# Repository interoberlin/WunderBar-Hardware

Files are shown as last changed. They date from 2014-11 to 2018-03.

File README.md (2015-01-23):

The WunderBar Schematics and Layout Repository
------------

Welcome to the **WunderBar Hardware Schematics and Layout** repository.
This repository contains the latest version of the *[WunderBar](https://relayr.io/wunderbar)* hardware design.
The *WunderBar* is manufactured by *[MikroElektronika](http://www.mikroe.com/wunderbar)*.   Manufacturing was sponsored by *[Conrad Electronics](http://www.conrad.de)*.

Here you will find everything you need to build your own version of the WunderBar. We encourage you to share, modify, extend and improve the existing design. Please reach out to us if you have any questions or need any help. We are eager to hear your feedback about the design, and suggestions as to how we might improve it.

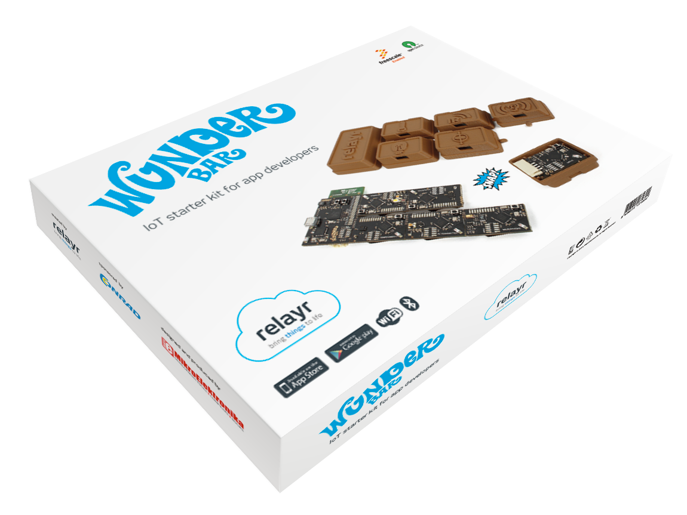
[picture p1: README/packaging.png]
WunderBar

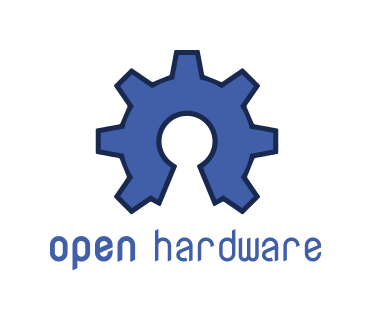
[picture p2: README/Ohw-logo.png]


### Datasheets:
In the *[/Datasheets](https://github.com/relayr/wunderbar-hardware/tree/master/Datasheets)* folder you will find the relevant data sheets for the micro controller units (MCUs), the sensors and the additional circuitry, separated by module type.

### Schematics:
The complete project for [*Altium Designer* <sup>TM</sup>](http://www.altium.com/altium-designer/overview) is located in the *[AltiumDesignerProject](https://github.com/relayr/wunderbar-hardware/tree/master/AltiumDesignerProject)* folder.

For a quick overview of the schematics for the Master Module and the 6 BLE modules, see the  *[WunderBar Schematics v1_3.pdf file](https://github.com/relayr/wunderbar-hardware/blob/master/WunderBar%20Schematics%20v1_3.pdf)*.

### Layout:
A PDF output of the PCB Layout can be found under *[Wunderbar Layout.pdf](https://github.com/relayr/wunderbar-hardware/blob/master/WunerBar%20Layout%20v1_3.pdf)*. For a detailed view of the different layers and connections see the *[Altium](http://www.altium.com/altium-designer/overview)* project.

### Bill of Materials:
The *[Bill of Materials v1_3](https://github.com/relayr/wunderbar-hardware/blob/master/Bill%20of%20Materials%20v1_3.xls)* sheet details the components' names, quantities, the suppliers' names and part numbers. See also the two files under *[/Manufacturing/BillOfMaterials](https://github.com/relayr/wunderbar-hardware/tree/master/Manufacturing/BillOfMaterials)* for a list view of the information in the Schematics file.

### Gerber Files:
The Gerber files output and the 'Pick and Place' configuration files are located inside the [*/Manufacturing*](https://github.com/relayr/wunderbar-hardware/tree/master/Manufacturing) folder.

### Acquiring the Files:
* To get the entire repository, download it as a **.zip** file from [here](https://github.com/relayr/wunderbar-hardware/archive/master.zip).

or

* If you have **git** installed simply access the folder where you want to download it and enter the following command:

	`git clone https://github.com/relayr/wunderbar-hardware.git`

We hope that you'd utilize the Wunderbar in your future projects. The realm of possibilities is as vast as your imagination!!!

### License:

	Copyright (c) 2014, Press Any Key UG and iThings4U GmbH

	All rights reserved.

	Redistribution and use in source and binary forms, with or without
	modification, are permitted provided that the following conditions are met:

	1. Redistributions of source code must retain the above copyright notice,
	this list of conditions and the following disclaimer.

	2. Redistributions in binary form must reproduce the above copyright notice,
	this list of conditions and the following disclaimer in the documentation
	and/or other materials provided with the distribution.

	3. Neither the name of the copyright holder nor the names of its contributors
	may be used to endorse or promote products derived from this software without
	specific prior written permission.

	THIS SOFTWARE IS PROVIDED BY THE COPYRIGHT HOLDERS AND CONTRIBUTORS "AS IS"
	AND ANY EXPRESS OR IMPLIED WARRANTIES, INCLUDING, BUT NOT LIMITED TO,
	THE IMPLIED WARRANTIES OF MERCHANTABILITY AND FITNESS FOR A PARTICULAR
	PURPOSE ARE DISCLAIMED. IN NO EVENT SHALL THE COPYRIGHT HOLDER OR CONTRIBUTORS
	BE LIABLE FOR ANY DIRECT, INDIRECT, INCIDENTAL, SPECIAL, EXEMPLARY,
	OR CONSEQUENTIAL DAMAGES (INCLUDING, BUT NOT LIMITED TO, PROCUREMENT
	OF SUBSTITUTE GOODS OR SERVICES; LOSS OF USE, DATA, OR PROFITS; OR BUSINESS
	INTERRUPTION) HOWEVER CAUSED AND ON ANY THEORY OF LIABILITY, WHETHER IN
	CONTRACT, STRICT LIABILITY, OR TORT (INCLUDING NEGLIGENCE OR OTHERWISE)
	ARISING IN ANY WAY OUT OF THE USE OF THIS SOFTWARE, EVEN IF ADVISED OF
	THE POSSIBILITY OF SUCH DAMAGE.

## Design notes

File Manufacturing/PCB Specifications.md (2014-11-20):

WunderBar Hardware
------------

### PCB Specifications:
* Material: FR-4,
* Thickness: 1.6mm,
* Layer count:4-layer,
* Extra details: Immersion Gold, 1oz finished copper, Black SolderMask, White Legend.

####NOTES:
* Layer sequence: GTL-G1-G2-GBL
* This design has blind bias: TX1 file represent holes between GTL and G1 layers

* We made the board panelized (3up) with 10mm routing between the boards vertically
* Panel Border should be 7mm wide with fiducial marks and tooling holes (3mm) distanced 2.5mm from the inner edge
* The size of the board is 115.723mm (W) x 39.421mm (H)
* The size of the panel should be 129.723mm (W) x 138.263mm (H)

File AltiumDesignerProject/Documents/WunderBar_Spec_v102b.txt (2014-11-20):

Specification:
FR-4, 1.6mm, 4-layer, Immersion Gold, 1oz finished copper, Black SolderMask, White Legend.
NOTES:
- Layer sequence: GTL-G1-G2-GBL
- This design has blind vias: TX1 file represent holes between GTL and G1 layers
- We need this board panelized (3up) with 10mm routing between the boards vertically
- Panel Border should be 7mm wide with fiducial marks and tooling holes (3mm) distanced 2.5mm from the inner edge
- NOTE: Panel already done
- The size of the board is 115.723mm (W) x 39.421mm (H)
- The size of the panel should be 129.723mm (W) x 138.263mm (H)

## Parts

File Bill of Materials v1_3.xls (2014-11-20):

# | Item Name | Quantity | Supplier Name | Package | Part Number
1 | 2450AT18A100E ANTENNA CHIP 2.4GHz SMD | 7 | DIGI-KEY CORPORATION | Tape & Reel (3Kpcs per Reel) | 2450AT18A100E
2 | 2450BM14A0002T 2.45Ghz balun low pass filter | 7 | DIGI-KEY CORPORATION | Tape & Reel (3Kpcs per Reel) | 2450BM140002T
3 | Battery Holder COIN CELL 20MM SMD | 5 | DIGI-KEY CORPORATION | Tape & Reel (700pcs per Reel) | BK-912-TR-ND
4 | Connector Header 2-pin for Li-Poly Battery SMD | 1 | DIGI-KEY CORPORATION | Tape & Reel (1Kpcs per Reel) | 455-1749-2-ND
5 | NRF51822-QFAA-G0 Bluetooth v4.0, Low Energy 48QFN SMD | 7 | RUTRONIK Elektronische Bauelemente GmbH | Tape & Reel (3Kpcs per Reel) | BTOOTH1233
6 | Tact Switch 4.60mm x 2.80mm SMD | 8 | DIGI-KEY CORPORATION | Digi-Reel | CKN10244DKR-ND
7 | 1nF Capacitor 0402 SMD | 14 | RUTRONIK Elektronische Bauelemente GmbH | Tape & Reel (10Kpcs per Reel) | KKK14629
8 | 100nF Capacitor 0402 SMD | 38 | RUTRONIK Elektronische Bauelemente GmbH | Tape & Reel (10Kpcs per Reel) | KKK16522
9 | 10uF Capacitor 0603 SMD | 14 | RUTRONIK Elektronische Bauelemente GmbH | Tape & Reel (4Kpcs per Reel) | KKS1047
10 | 10pF Capacitor 0402 SMD | 15 | RUTRONIK Elektronische Bauelemente GmbH | Tape & Reel (10Kpcs per Reel) | KKK14556
11 | 47nF Capacitor 0402 SMD | 7 | RUTRONIK Elektronische Bauelemente GmbH | Tape & Reel (10Kpcs per Reel) | KKK20252
12 | 12pF Capacitor 0402 SMD | 18 | RUTRONIK Elektronische Bauelemente GmbH | Tape & Reel (10Kpcs per Reel) | KKK14879
13 | 1uF Capacitor 0402 SMD | 5 | RUTRONIK Elektronische Bauelemente GmbH | Tape & Reel (10Kpcs per Reel) | KKS3215
14 | 10nF Capacitor 0402 SMD | 1 | RUTRONIK Elektronische Bauelemente GmbH | Tape & Reel (10Kpcs per Reel) | KKK16335
15 | 8pF Capacitor 0402 SMD | 1 | DIGI-KEY CORPORATION | Tape & Reel (10Kpcs per Reel) | 445-4891-2-ND
16 | 2.2uF Capacitor 0603 SMD | 1 | RUTRONIK Elektronische Bauelemente GmbH | Tape & Reel (4Kpcs per Reel) | KKK18480
17 | SD0603S040S0R2 DIODE SCHOTTKY 40V 0.2A 0603 SMD | 1 | DIGI-KEY CORPORATION | Tape & Reel (3Kpcs per Reel) | 478-7798-2-ND
18 | PCA9306 I2C Voltage translator US8 SMD | 1 | DIGI-KEY CORPORATION | Tape & Reel (3Kpcs per Reel) | 296-17988-2-ND
19 | ZXLD383 LED driver white backlght SOT23-5 SMD | 1 | DIGI-KEY CORPORATION | Tape & Reel (3Kpcs per Reel) | ZXLD383ET5TR-ND
20 | 10uH Inductor 4x4mm 1.2A SMD | 1 | DIGI-KEY CORPORATION | Tape & Reel (3500pcs per Reel) | 587-2886-2-ND
21 | 47uH Inductor 20% 75mA 0805 SMD | 1 | DIGI-KEY CORPORATION | Tape & Reel (3Kpcs per Reel) | 587-2047-2-ND
22 | LED Yellow - 0402 SMD | 10 | DIGI-KEY CORPORATION | Tape & Reel (2Kpcs per Reel) | SML-LX0402SYC-TR
23 | SFH4441 LED IR EMITTER 950NM SMD | 2 | MOUSER ELECTRONICS | Tape & Reel (3Kpcs per Reel) | 720-SFH4441
24 | LED White - 1206 SMD | 1 | DIGI-KEY CORPORATION | Tape & Reel (2Kpcs per Reel) | 45-21/LK2C-B38452C4CB2/2T
25 | Grove connector 4pin original 1125R-4P | 1 | Seeed Technology Inc. | Bulk (10pcs per pack) | 1125R-4P
26 | LTC4081DFN Li-Ion battery charger and buck regulator SMD | 1 | DIGI-KEY CORPORATION | Tape & Reel | LTC4081EDD#TRPBF
27 | 95K3 ohm Resistor 0402 SMD | 1 | DIGI-KEY CORPORATION | Tape & Reel (10Kpcs per Reel) | RMCF0402FT95K3TR-ND
28 | 300K ohm Resistor 0402 SMD | 1 | DIGI-KEY CORPORATION | Tape & Reel (10Kpcs per Reel) | 311-300KLRTR-ND
29 | 1K69 Ohm Resistor 0402 SMD | 1 | RUTRONIK Elektronische Bauelemente GmbH | Tape & Reel (10Kpcs per Reel) | WRC47924
30 | 220 ohm Resistor 0402 SMD | 1 | RUTRONIK Elektronische Bauelemente GmbH | Tape & Reel (10Kpcs per Reel) | WRC33968
31 | 22 ohm Resistor 0402 SMD | 3 | RUTRONIK Elektronische Bauelemente GmbH | Tape & Reel (10Kpcs per Reel) | WRC33949
32 | 10K ohm Resistor 0402 SMD | 30 | RUTRONIK Elektronische Bauelemente GmbH | Tape & Reel (10Kpcs per Reel) | WRC34004
33 | 20 ohm 0.25W Resistor 1206 SMD | 1 | RUTRONIK Elektronische Bauelemente GmbH | Tape & Reel (5Kpcs per Reel) | WRC31529
34 | 100 ohm Resistor 0402 SMD | 7 | RUTRONIK Elektronische Bauelemente GmbH | Tape & Reel (10Kpcs per Reel) | WRC33961
35 | 4K7 Ohm Resistor 0402 SMD | 2 | RUTRONIK Elektronische Bauelemente GmbH | Tape & Reel (10Kpcs per Reel) | WRC33997
36 | 1M ohm Resistor 0603 SMD | 1 | RUTRONIK Elektronische Bauelemente GmbH | Tape & Reel (5Kpcs per Reel) | WRC32820
37 | 10K ohm Resistor 0603 SMD | 1 | RUTRONIK Elektronische Bauelemente GmbH | Tape & Reel (5Kpcs per Reel) | WRC32607
38 | 100K ohm Resistor 0402 SMD | 4 | RUTRONIK Elektronische Bauelemente GmbH | Tape & Reel (10Kpcs per Reel) | WRC34084
39 | HTU21D Humidity and Temp. sensor QFN SMD | 1 | DIGI-KEY CORPORATION | Tape & Reel | HTU21D
40 | MPU-6500 6-axis gyro and accelerometer SMD | 1 | DIGI-KEY CORPORATION | Tape & Reel | MPU-6500
41 | TCS37717FN RGB Color Sensing and Proximity SMD | 1 | DIGI-KEY CORPORATION | Digi-Reel | TCS37717FNDKR-ND
42 | AO3418 MOSFET N-CH 30V 3.8A SOT23 | 2 | DIGI-KEY CORPORATION | Tape & Reel (3Kpcs per Reel) | AO3418
43 | MK24FN1M0VDC12 MCU | 1 | DIGI-KEY CORPORATION | CutTape | MK24FN1M0VDC12RCT-ND
44 | MicroPhone 3.76mmx 2.24mm SMD | 1 | DIGI-KEY CORPORATION | Tape & Reel (1200pcs per Reel) | 423-1165-2-ND
45 | LTC1966 RMS to DC Converter MSOP-8 SMD | 1 | DIGI-KEY CORPORATION | Tube (50pcs per Tube) | LTC1966CMS8#PBF-ND
46 | TLV2760 General Purpose OP.Amp. DBV6 SMD | 1 | DIGI-KEY CORPORATION | Tape & Reel | TLV2760IDBVT
47 | TPS22924C Load Switch 2A YZP6 SMD | 1 | DIGI-KEY CORPORATION | Tape & Reel (3Kpcs per Reel) | 296-25510-2-ND
48 | USB Micro AB Socket Right Angle SMD | 1 | DIGI-KEY CORPORATION | Tape & Reel (3500pcs per Reel) | H11635TR-ND
49 | MCP1801 Fixed Positive Regulator SOT23-5 SMD | 1 | DIGI-KEY CORPORATION | Tape & Reel (3Kpcs per Reel) | MCP1801T-3302I/OTTR-ND
50 | GS1500M WiFi Module | 1 | GLYN GmbH & Co. KG | Single pcs | GS1500M_v22
51 | 32.768Khz Crystal 12.5 pF 1206 SMD | 8 | RUTRONIK Elektronische Bauelemente GmbH | Tape & Reel (1Kpcs per Reel) | QUARZ2785
52 | 12Mhz Crystal 12pF 3.2x2.5 SMD | 1 | DIGI-KEY CORPORATION | Tape & Reel (3Kpcs per Reel) | 887-1458-2-ND
53 | 16Mhz Crystal 10pF 2.5x2mm SMD | 7 | DIGI-KEY CORPORATION | Tape & Reel (3Kpcs per Reel) | 535-10923-2-ND
54 | 3K74 ohm Resistor 0402 SMD | 1 | DIGI-KEY CORPORATION | Tape & Reel (10Kpcs per Reel) | 311-3.74KLRTR-ND
55 | 0 ohm Resistor 0402 SMD | 1 | DIGI-KEY CORPORATION | Tape & Reel (10Kpcs per Reel) | P0.0JTR-ND
56 | 0 Ohm Resistor 0805 SMD | 1 | RUTRONIK Elektronische Bauelemente GmbH | Tape & Reel (5Kpcs per Reel) | WRC31353
57 | 2K94 Ohm Resistor 0402 SMD | 1 | DIGI-KEY CORPORATION | Tape & Reel (10Kpcs per Reel) | 541-2.94KLTR-ND
58 | WunderBar_v102.pcb | 1 | Accredo Logistics d.o.o. | Panel (3up) | WunderBar_Panel_v102b
59 | 10K ohm Resistor 0.1% 0402 SMD | 4 | RUTRONIK Elektronische Bauelemente GmbH | Tape & Reel (10Kpcs per Reel) | WPR1669
60 | Double sided foam tape cut to 25mmx35.5mm | 6 | Dongguan Yihong Packing Materials Factory | Single pcs | YH140517
61 | Battery 3V CR2032 | 5 | RUTRONIK Elektronische Bauelemente GmbH | Tray | BAT2973
62 | Li-Polymer Battery 3.7V 130mA with JST-PHR-2 connector | 1 | W & P INTERNATIONAL TRADING LIMITED | Single pcs | HPL302030
63 | Box WunderBar | 1 | Bigraf plus |  | Box WunderBar
64 | Flajer – WunderBar | 1 | Bigraf plus |  | Flajer – WunderBar
65 | Flajer – WunderBar Master and Sensor assembly | 1 | Bigraf plus |  | Flajer – WunderBar Master and Sensor assembly
66 | Flajer – WunderBar Master and Sensor LEDs and buttons | 1 | Bigraf plus |  | Flajer – WunderBar Master and Sensor LEDs and buttons
67 | FOAM – Wunder Bar 1 (chocolate casing part) | 1 | Dongguan Yihong Packing Materials Factory |  | FOAM – Wunder Bar 1 (chocolate casing part)
68 | FOAM – Wunder Bar 2 (accessories part) | 1 | Dongguan Yihong Packing Materials Factory |  | FOAM – Wunder Bar 2 (accessories part)
69 | Wunder Bar karton PULL OUT | 1 | Bigraf plus |  | Wunder Bar karton PULL OUT
70 | USB A Male to micro USB B Male 0.2m Cable black | 1 | DANGOS INTERNATIONAL CO., LIMITED | Bulk 100pcs/bag | USB A Male to Male micro B
71 | 750 Ohm Resistor 0402 SMD | 1 | DIGI-KEY CORPORATION | Tape & Reel (10Kpcs per Reel) | 311-750LRTR-ND
72 | 470 Ohm Resistor 0402 SMD | 8 | RUTRONIK Elektronische Bauelemente GmbH | Tape & Reel (10Kpcs per Reel) | WRC33975

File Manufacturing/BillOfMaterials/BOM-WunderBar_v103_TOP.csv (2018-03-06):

Comment | Designator
100 0402 | R30
100 0402 | R43
100 0402 | R52
100 0402 | R54
100 0402 | R55
100 0402 | R57
100 0402 | R58
100k 0402 | R62
100k 0402 | R67
100k 0402 | R68
100nF 0402 | C101
100nF 0402 | C106
100nF 0402 | C107
100nF 0402 | C108
100nF 0402 | C109
100nF 0402 | C113
100nF 0402 | C114
100nF 0402 | C12
100nF 0402 | C19
100nF 0402 | C2
100nF 0402 | C20
100nF 0402 | C3
100nF 0402 | C30
100nF 0402 | C31
100nF 0402 | C32
100nF 0402 | C38
100nF 0402 | C4
100nF 0402 | C40
100nF 0402 | C42
100nF 0402 | C43
100nF 0402 | C44
100nF 0402 | C5
100nF 0402 | C50
100nF 0402 | C52
100nF 0402 | C53
100nF 0402 | C54
100nF 0402 | C6
100nF 0402 | C63
100nF 0402 | C64
100nF 0402 | C65
100nF 0402 | C72
100nF 0402 | C73
100nF 0402 | C74
100nF 0402 | C80
100nF 0402 | C84
100nF 0402 | C85
100nF 0402 | C88
100nF 0402 | C89
10k 0402 | R10
10k 0402 | R11
10k 0402 | R12
10K 0402 | R14
10K 0402 | R15
10K 0402 | R16
10k 0402 | R19
10k 0402 | R20
10k 0402 | R21
10k 0402 | R23
10k 0402 | R24
10k 0402 | R26
10k 0402 | R31
10k 0402 | R32
10k 0402 | R33
10k 0402 | R34
10k 0402 | R35
10k 0402 | R36
10k 0402 | R37
10K 0402 | R38
10K 0402 | R39
10K 0402 | R40
10K 0402 | R41
10k 0402 | R44
10k 0402 | R45
10k 0402 | R46
10k 0402 | R47
10k 0402 | R48
10k 0.1% 0402 | R60
10k 0.1% 0402 | R63
10k 0.1% 0402 | R64
10k 0.1% 0402 | R66
10k 0402 | R69
10k 0402 | R8
10k 0402 | R9
10k 0603 | R61
10nF 0402 | C39
10pF 0402 | C11
10pF 0402 | C14
10pF 0402 | C15
10pF 0402 | C22
10pF 0402 | C23
10pF 0402 | C34
10pF 0402 | C35
10pF 0402 | C46
10pF 0402 | C47
10pF 0402 | C56
10pF 0402 | C57
10pF 0402 | C67
10pF 0402 | C68
10pF 0402 | C76
10pF 0402 | C77
10uH INDUCTOR_40X40 | L1
10µF 0603 | C10
10µF 0603 | C25
10µF 0603 | C28
10µF 0603 | C37
10µF 0603 | C49
10µF 0603 | C59
10µF 0603 | C60
10µF 0603 | C61
10µF 0603 | C79
10µF 0603 | C8
10µF 0603 | C81
10µF 0603 | C86
10µF 0603 | C87
10µF 0603 | C9
12MHz 12pF ABM8G | Y1
12pF 0402 | C100
12pF 0402 | C102
12pF 0402 | C103
12pF 0402 | C104
12pF 0402 | C105
12pF 0402 | C17
12pF 0402 | C18
12pF 0402 | C70
12pF 0402 | C90
12pF 0402 | C91
12pF 0402 | C92
12pF 0402 | C93
12pF 0402 | C94
12pF 0402 | C95
12pF 0402 | C96
12pF 0402 | C97
12pF 0402 | C98
12pF 0402 | C99
16MHz 10pF CRYSTAL25X20 | Y2
16MHz 10pF CRYSTAL25X20 | Y3
16MHz 10pF CRYSTAL25X20 | Y4
16MHz 10pF CRYSTAL25X20 | Y5
16MHz 10pF CRYSTAL25X20 | Y6
16MHz 10pF CRYSTAL25X20 | Y7
16MHz 10pF CRYSTAL25X20 | Y8
1M 0402 | R65
1M 0603 | R59
1nF 0402 | C1
1nF 0402 | C16
1nF 0402 | C24
1nF 0402 | C29
1nF 0402 | C36
1nF 0402 | C41
1nF 0402 | C48
1nF 0402 | C51
1nF 0402 | C58
1nF 0402 | C62
1nF 0402 | C69
1nF 0402 | C7
1nF 0402 | C71
1nF 0402 | C78
1uF 0402 | C111
1uF 0402 | C112
1uF 0402 | C26
1uF 0402 | C27
1uF 0402 | C83
2.2uF 0603 | C110
20 0.2W 1206_MINIMELF_COMBO | R27
22 0402 | R6
22 0402 | R70
22 0402 | R71
470 0402 | R13
470 0402 | R17
470 0402 | R18
470 0402 | R22
470 0402 | R25
470 0402 | R28
470 0402 | R29
2k94 0402 | R3
750 0402 | R4
470 0402 | R5
220 0402 | R7
2450AT18A100E | ANT1
2450AT18A100E | ANT2
2450AT18A100E | ANT3
2450AT18A100E | ANT4
2450AT18A100E | ANT5
2450AT18A100E | ANT6
2450AT18A100E | ANT7
2450BM14A0002T | BALUN
2450BM14A0002T | BALUN1
2450BM14A0002T | BALUN2
2450BM14A0002T | BALUN3
2450BM14A0002T | BALUN4
2450BM14A0002T | BALUN5
2450BM14A0002T | BALUN6
300k 0402 | R2
32.768 KHz 1206_MINIMELF_COMBO | X1
32.768 KHz 1206_MINIMELF_COMBO | X2
32.768 KHz 1206_MINIMELF_COMBO | X3
32.768 KHz 1206_MINIMELF_COMBO | X4
32.768 KHz 1206_MINIMELF_COMBO | X5
32.768 KHz 1206_MINIMELF_COMBO | X6
32.768 KHz 1206_MINIMELF_COMBO | X7
32.768 KHz 1206_MINIMELF_COMBO | X8
47nF 0402 | C13
47nF 0402 | C21
47nF 0402 | C33
47nF 0402 | C45
47nF 0402 | C55
47nF 0402 | C66
47nF 0402 | C75
47uH 0805_MICROMELF_COMBO | L2
10k 0402 | R42
4k7 0402 | R49
4k7 0402 | R50
3k74 0402 | R51
0R 0402 | R53
8pF 0402 | C82
95k3 0402 | R1
AO3418 SOT23 | T1
AO3418 SOT23 | T2
HTU21D | SENSE1
LTC1966 MSOP-8 | U3
LTC4081DFN | PWR1
MCP1801T-3302 SOT-23-5 | VREG2
MK24FN1M0VDC12 BGA121-0.65 | U1
MPU6500QFN QFN24-0.4 | SENSE2
NRF51822QFN48 QFN48_EP | BT
NRF51822QFN48 QFN48_EP | BT1
NRF51822QFN48 QFN48_EP | BT2
NRF51822QFN48 QFN48_EP | BT3
NRF51822QFN48 QFN48_EP | BT4
NRF51822QFN48 QFN48_EP | BT5
NRF51822QFN48 QFN48_EP | BT6
PCA9306 US8 | IC2
0R 0805 | R72
SD0603S040S0R2 0603_POLAR | D2
SFH4441 MIDLED | LED10
SFH4441 MIDLED | LED6
SPQ0410HR5H-B | U2
Tact Sw 4.6x2.8 | BTN1
Tact Sw 4.6x2.8 | BTN2
Tact Sw 4.6x2.8 | BTN3
Tact Sw 4.6x2.8 | BTN4
Tact Sw 4.6x2.8 | BTN5
Tact Sw 4.6x2.8 | BTN6
Tact Sw 4.6x2.8 | PGM
Tact Sw 4.6x2.8 | RST
TCS37717FN | SENSE3
TLV2760 DBV-6 | U4
TPS22924C YZP-6 | U5
USB MICRO AB USB_MICRO_SMD | USB
White LED3X2 | LED13
YELLOW 0402_POLAR | LED1
YELLOW 0402_POLAR | LED11
YELLOW 0402_POLAR | LED12
YELLOW 0402_POLAR | LED2
YELLOW 0402_POLAR | LED3
YELLOW 0402_POLAR | LED4
YELLOW 0402_POLAR | LED5
YELLOW 0402_POLAR | LED7
YELLOW 0402_POLAR | LED8
YELLOW 0402_POLAR | LED9
ZXLD383 SOT-23-5 | IC3

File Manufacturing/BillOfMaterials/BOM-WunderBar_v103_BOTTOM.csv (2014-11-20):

Comment | Designator
BATTERYBK-912 | BAT1
BATTERYBK-912 | BAT2
BATTERYBK-912 | BAT3
BATTERYBK-912 | BAT4
BATTERYBK-912 | BAT5
GS1500M | WIFI
HDR-1X2JST-PH-H | BATT

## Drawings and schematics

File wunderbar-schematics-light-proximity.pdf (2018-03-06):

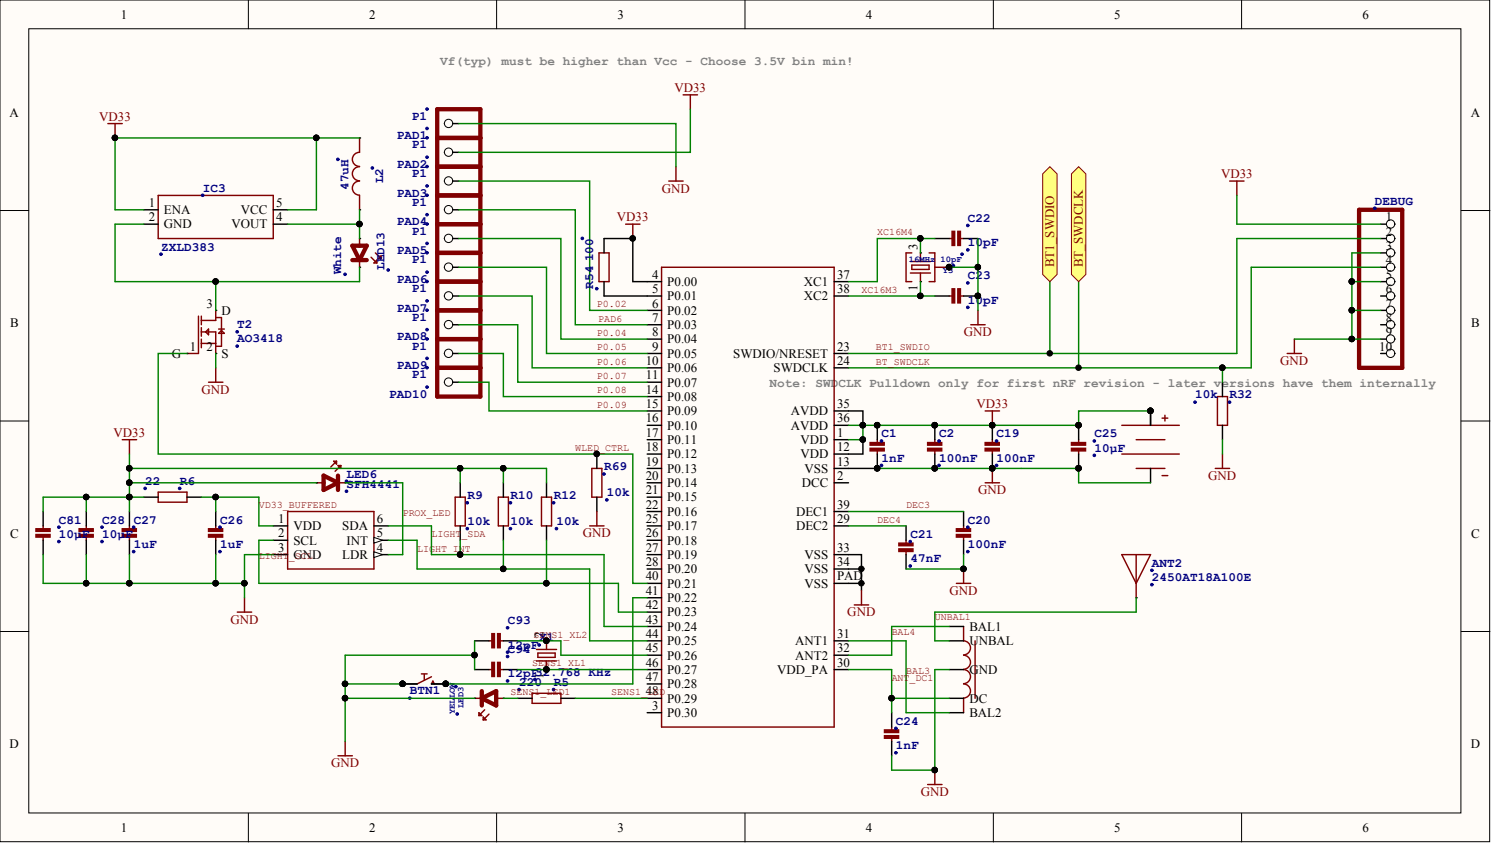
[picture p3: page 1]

Vf(typ) must be higher than Vcc - Choose 3.5V bin min!

Note: SWDCLK Pulldown only for first nRF revision - later versions have them internally
VDD
DCC

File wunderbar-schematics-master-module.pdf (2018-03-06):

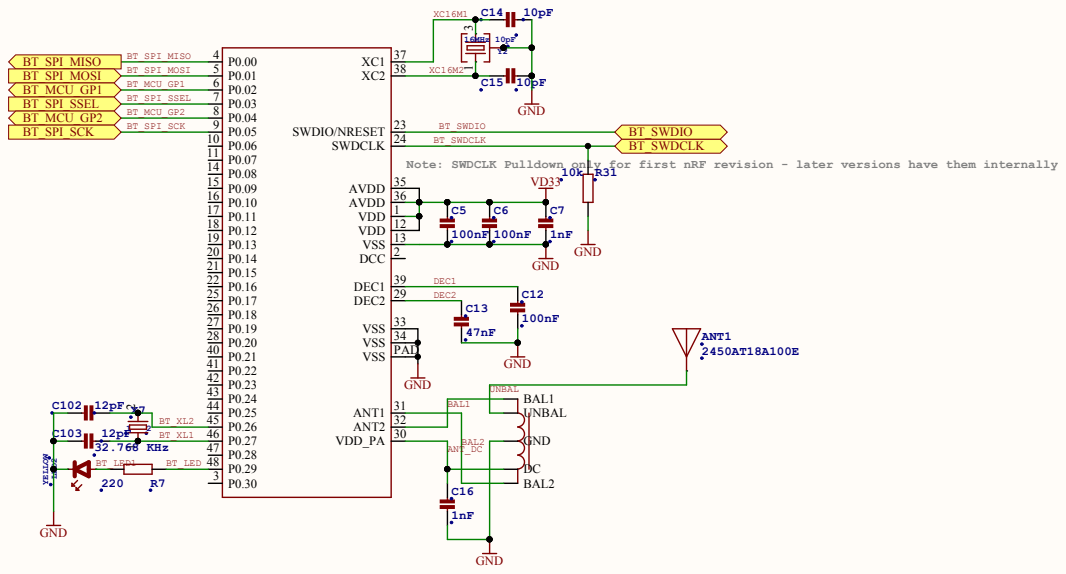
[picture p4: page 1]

Note: SWDCLK Pulldown only for first nRF revision - later versions have them internally

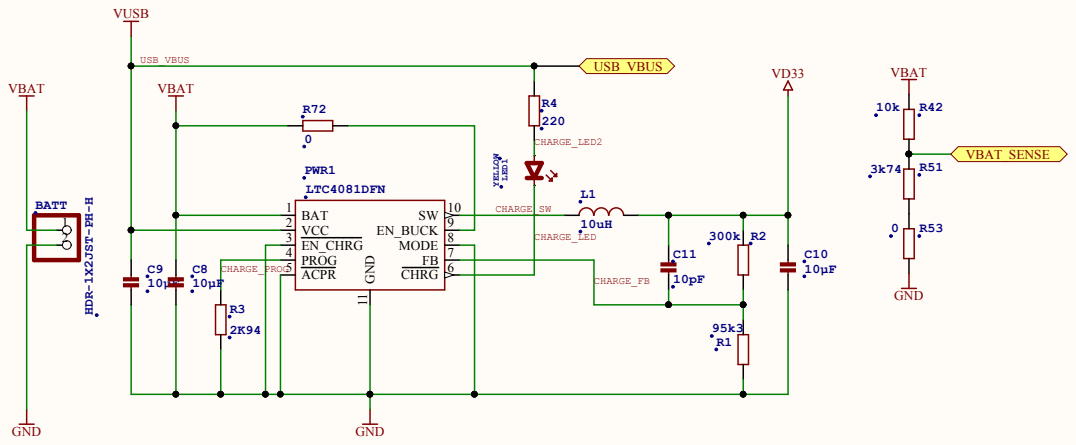
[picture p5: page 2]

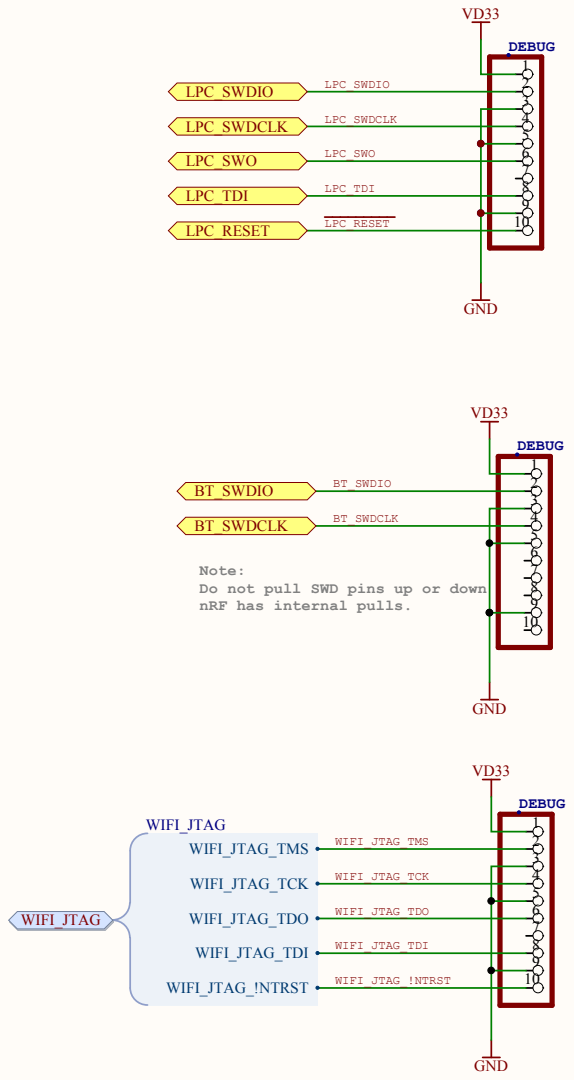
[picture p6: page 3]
DEBUG; GND; LPC_SWDIO; LPC_SWDCLK; LPC_RESET; LPC_SWO; LPC_TDI; BT_SWDCLK; BT_SWDIO; WIFI_JTAG_TMS; WIFI_JTAG_TCK; WIFI_JTAG_TDO; WIFI_JTAG_TDI; WIFI_JTAG_!NTRST; WIFI_JTAG

Note:
Do not pull SWD pins up or down
nRF has internal pulls.

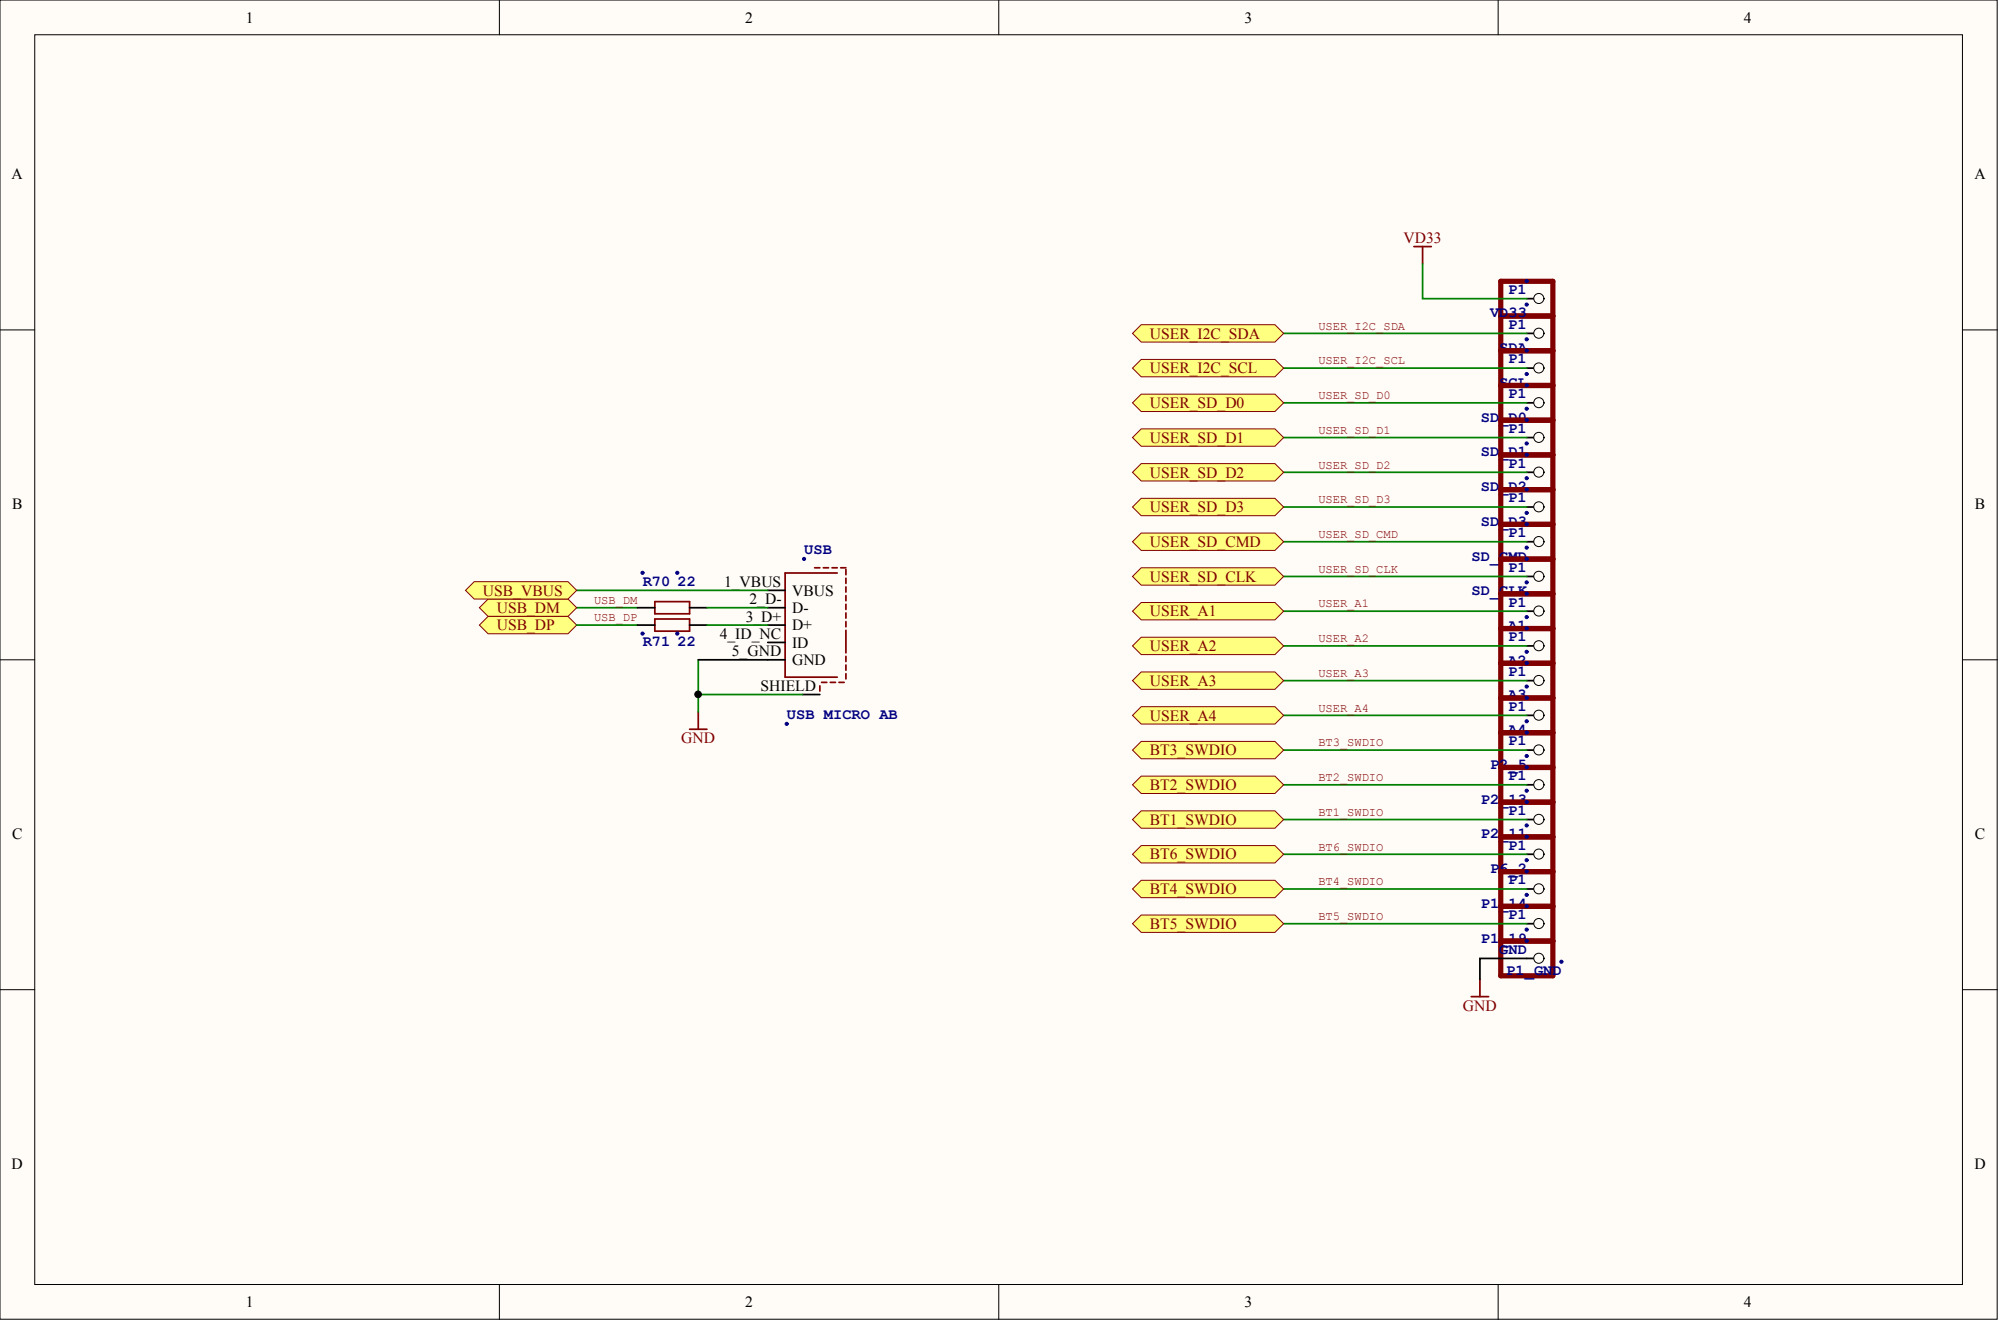
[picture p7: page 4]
VBUS 1_VBUS D- 2_D- D+ 3_D+; GND 5_GND; SHIELD; USB; SDA; SCL; SD_CMD; SD_CLK; GND; USB_DP; USB_DM; USER_I2C_SDA; USER_I2C_SCL; USER_SD_D0; USER_SD_D1; USER_SD_D2; USER_SD_D3; USER_SD_CMD; USER_SD_CLK; USER_A1; USER_A2; USER_A3; USER_A4; BT3_SWDIO; BT2_SWDIO; BT1_SWDIO; BT6_SWDIO; BT4_SWDIO; BT5_SWDIO; USB_DM USB_DP; USB_VBUS; P1_GND

USB MICRO AB

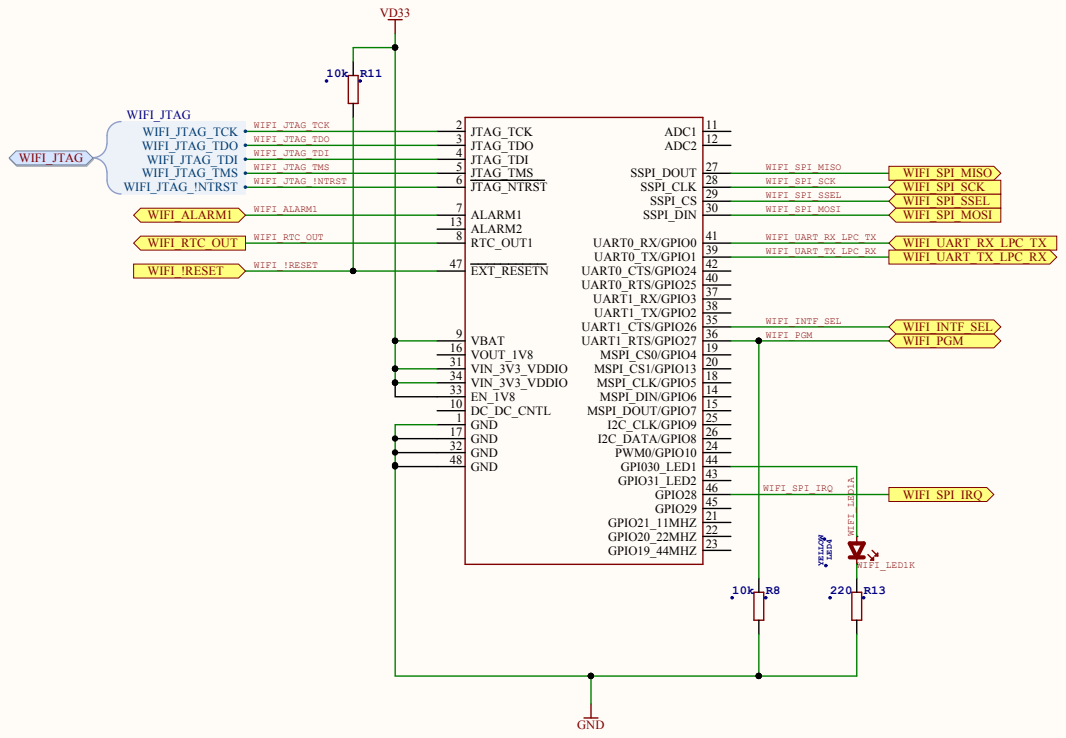
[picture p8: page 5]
JTAG_TCK 2 JTAG_TDO 3 JTAG_TDI 4 JTAG_TMS 5 JTAG_NTRST 6; ALARM1 7 ALARM2 13 RTC_OUT1 8; ADC1; ADC2; SSPI_DOUT; SSPI_CLK; SSPI_CS; SSPI_DIN; EXT_RESETN 47; UART0_RX/GPIO0; UART0_TX/GPIO1; UART0_RTS/GPIO25; 40 UART0_CTS/GPIO24; UART1_RX/GPIO3; UART1_TX/GPIO2; UART1_CTS/GPIO26; UART1_RTS/GPIO27; MSPI_CS0/GPIO4; MSPI_CS1/GPIO13; MSPI_CLK/GPIO5; MSPI_DOUT/GPIO7; 15 MSPI_DIN/GPIO6; I2C_CLK/GPIO9; I2C_DATA/GPIO8; PWM0/GPIO10; GPI030_LED1; GPIO31_LED2; GPIO29; 45 GPIO28; GPIO21_11MHZ; GPIO20_22MHZ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

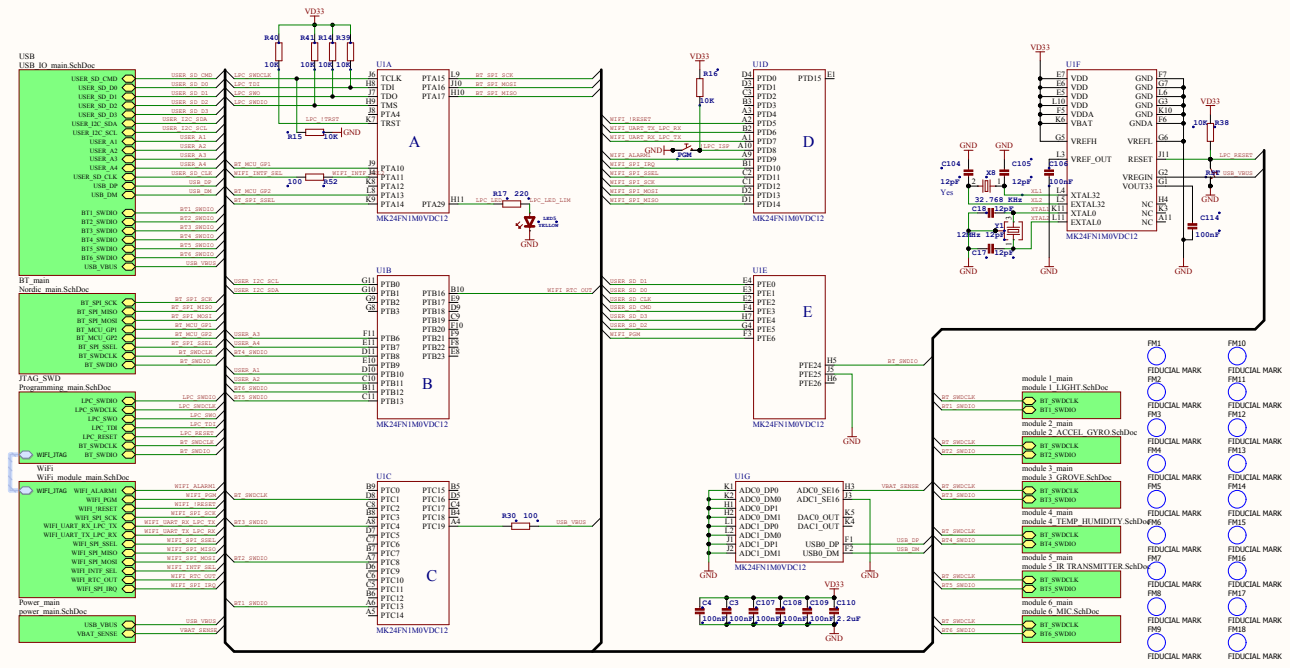
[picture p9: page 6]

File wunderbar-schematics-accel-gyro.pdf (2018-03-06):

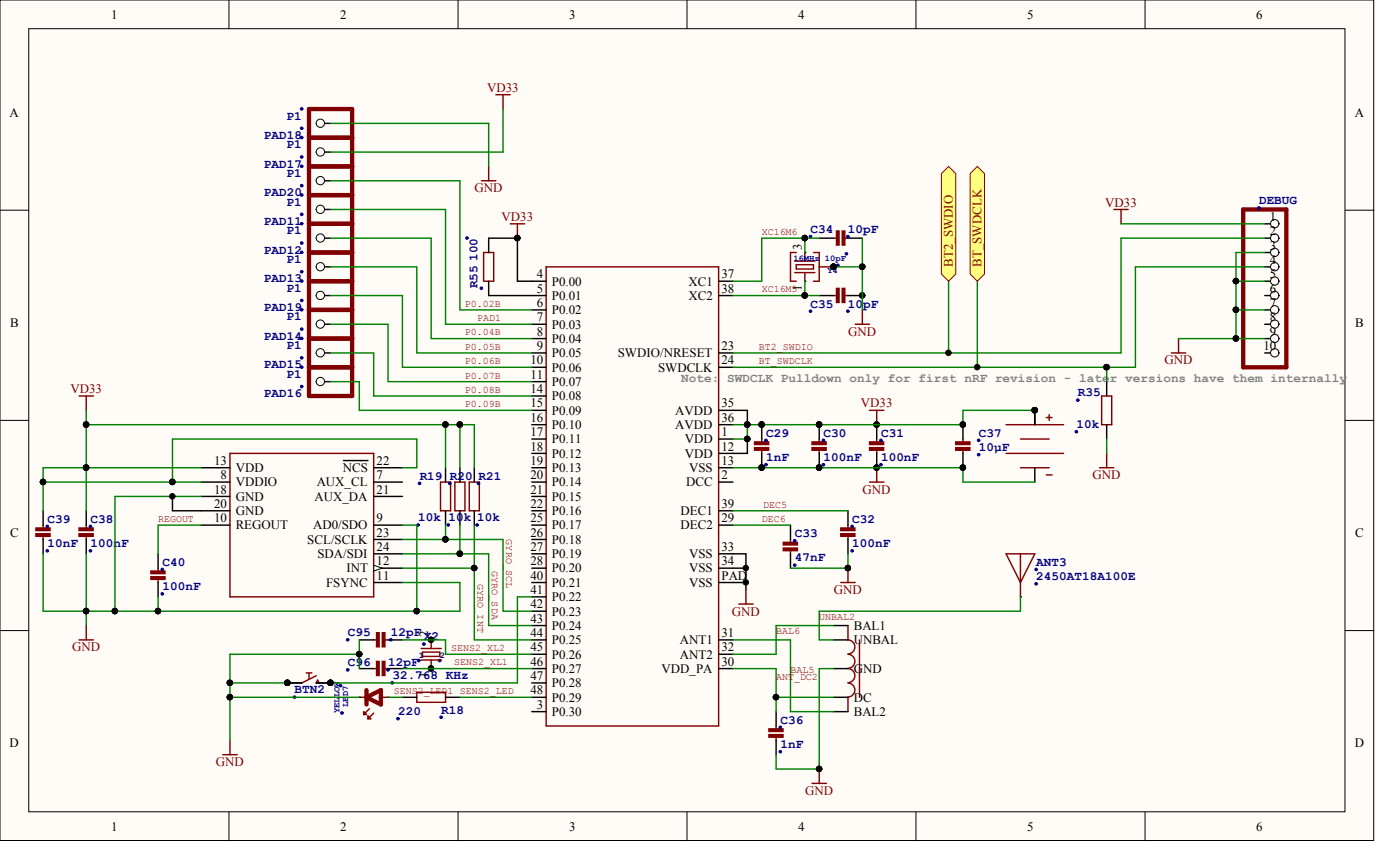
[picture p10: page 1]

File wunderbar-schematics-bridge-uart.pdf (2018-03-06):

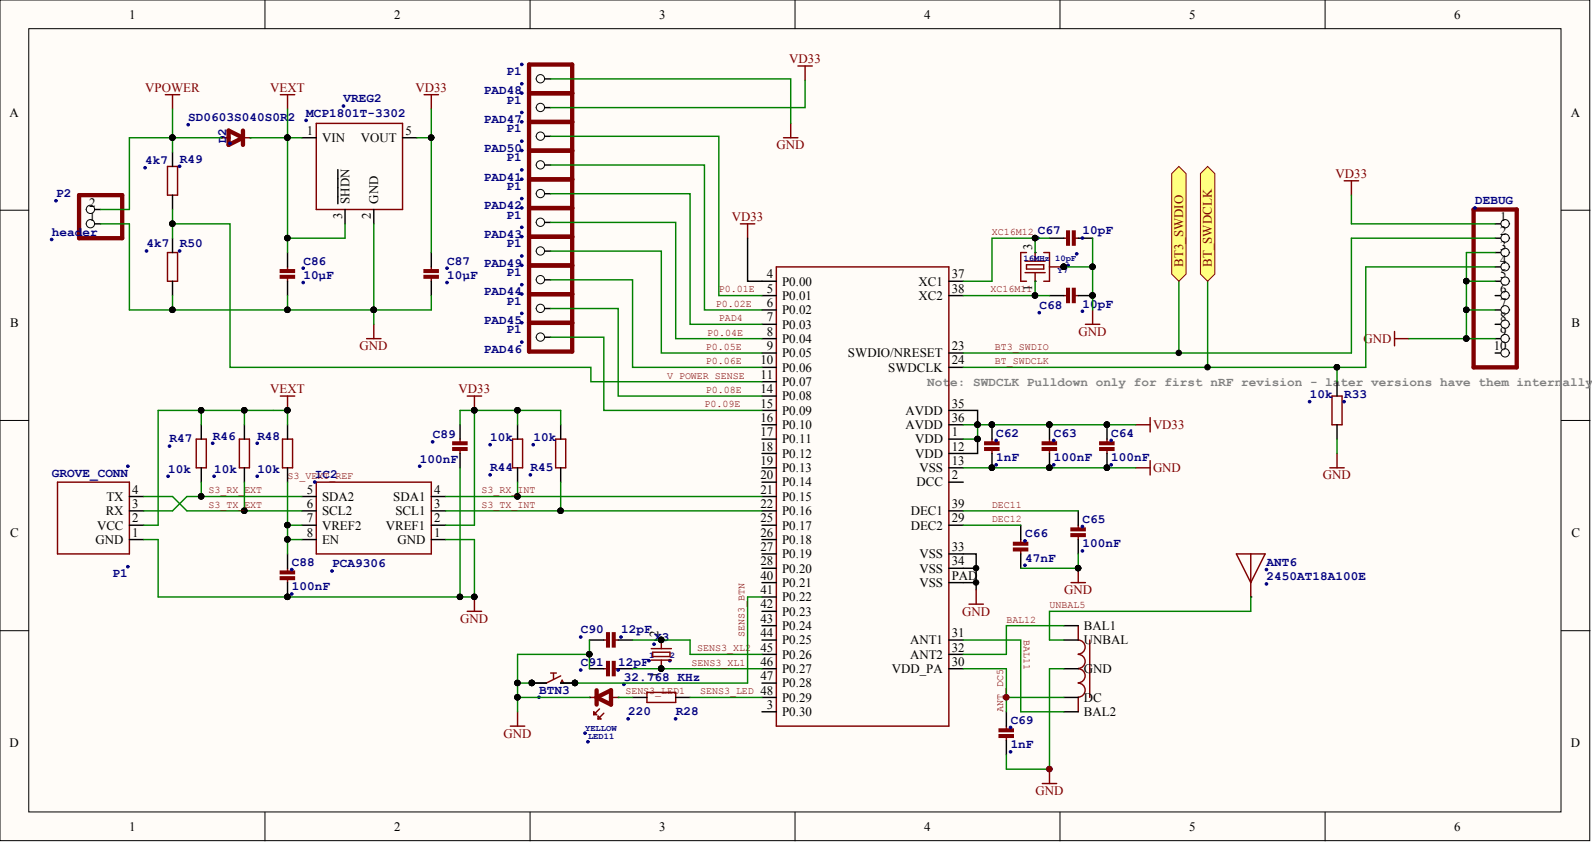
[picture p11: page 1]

Note: SWDCLK Pulldown only for first nRF revision - later versions have them internally
VDD
DCC

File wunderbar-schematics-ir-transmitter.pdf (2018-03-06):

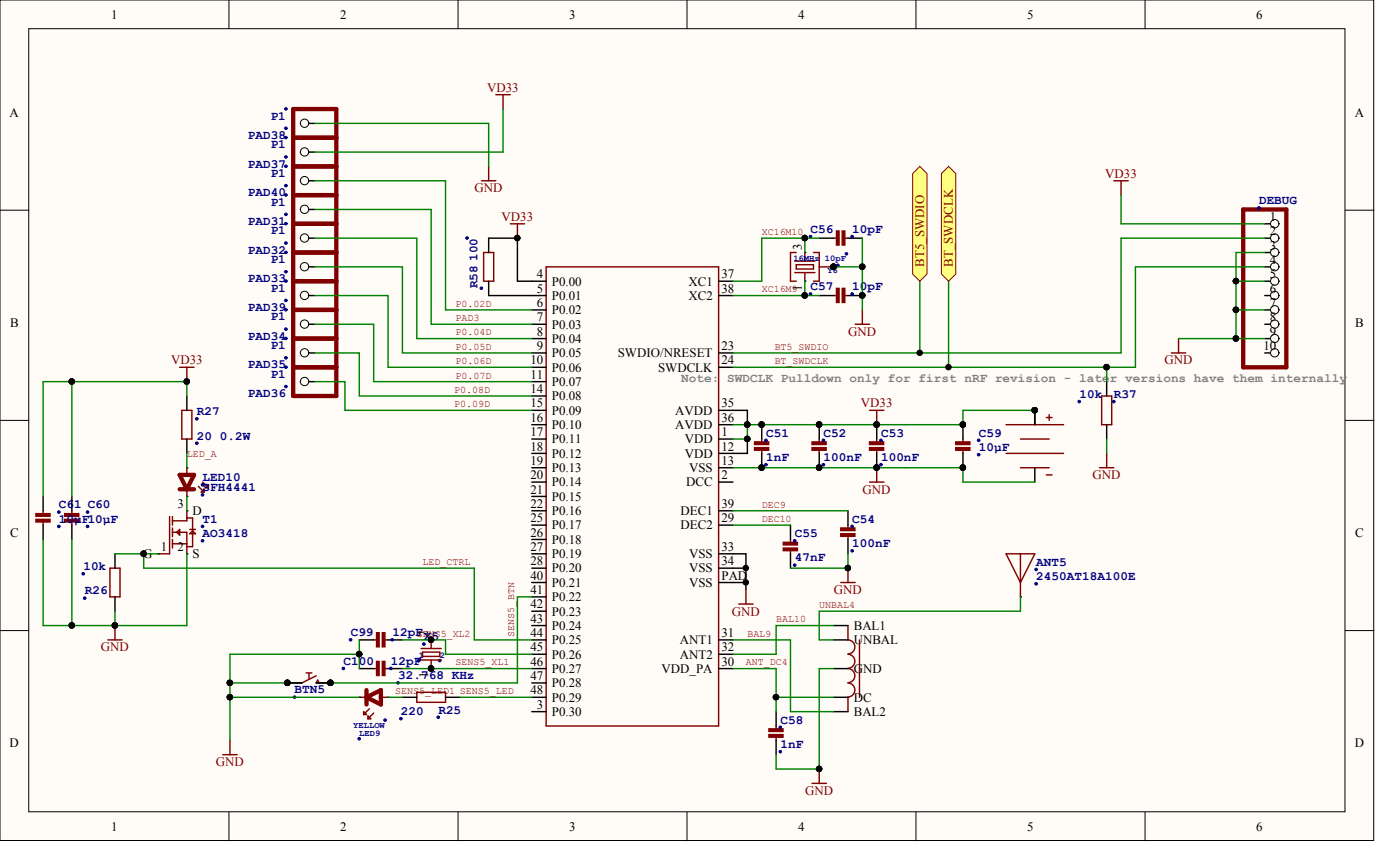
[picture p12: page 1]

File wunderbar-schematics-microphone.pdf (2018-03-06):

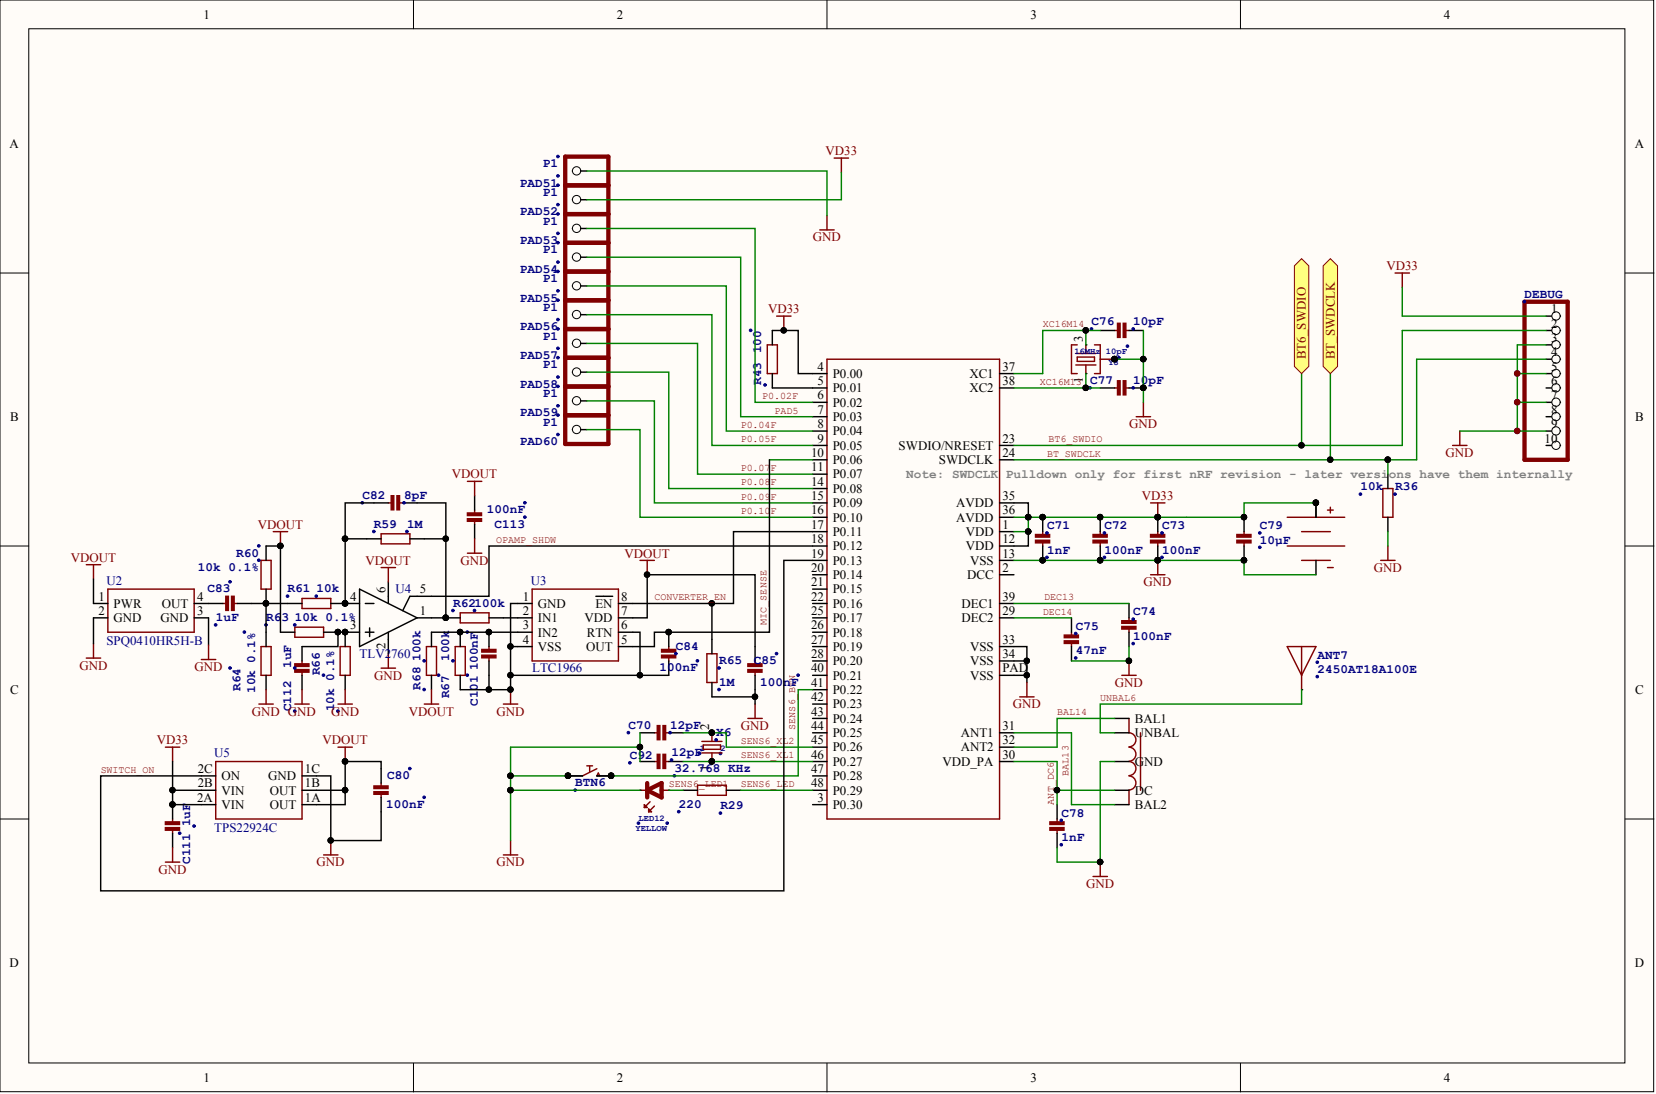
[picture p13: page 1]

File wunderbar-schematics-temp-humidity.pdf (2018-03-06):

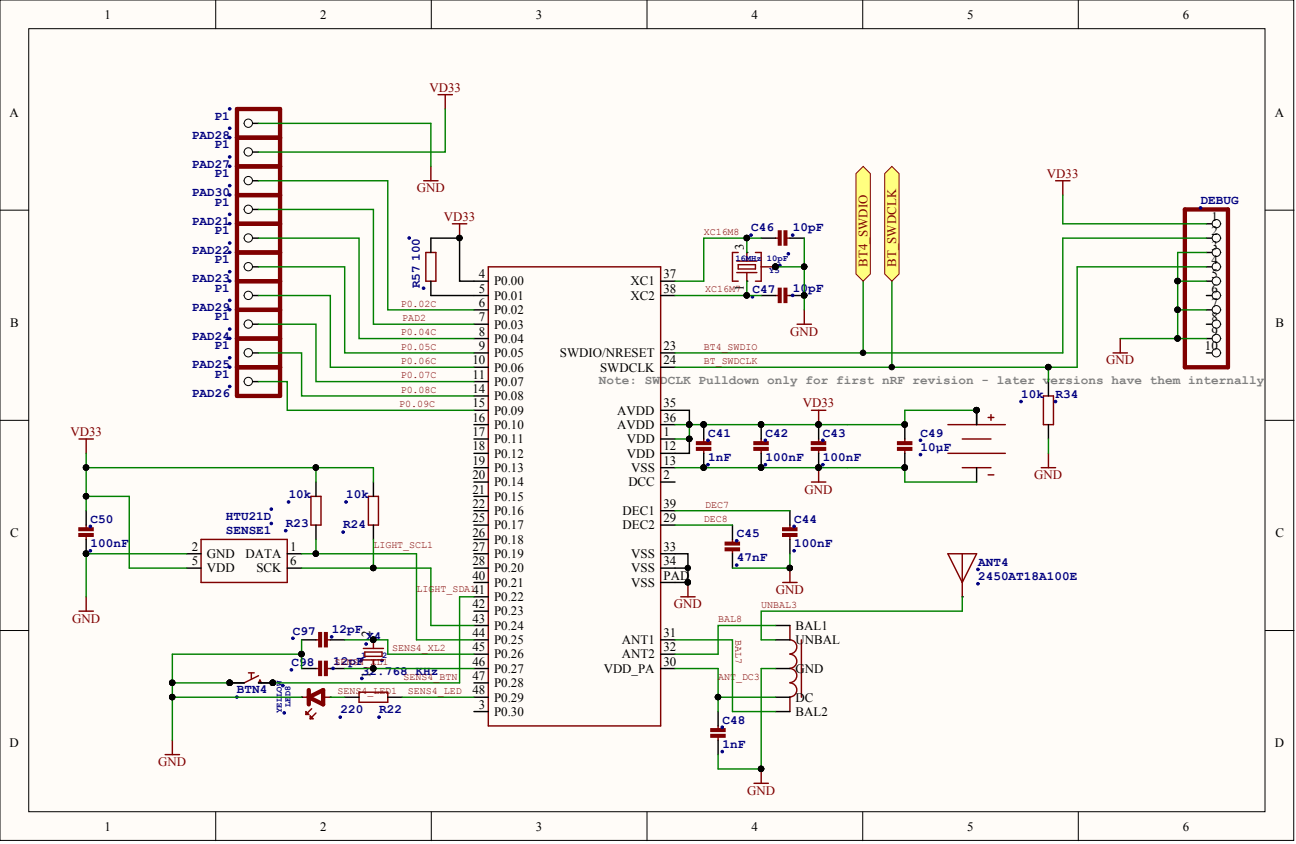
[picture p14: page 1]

Note: SWDCLK Pulldown only for first nRF revision - later versions have them internally


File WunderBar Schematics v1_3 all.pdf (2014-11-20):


Vf(typ) must be higher than Vcc - Choose 3.5V bin min!

PAD6 P0.04 | 7 8

Note: SWDCLK Pulldown only for first nRF revision - later versions have them internally
VDD
DCC


PAD1 P0.04B | 7 8


P0.02E | 6 | | GND BT3_SWDIO
PAD4 | 7
P0.04E P0.05E | 8 9

P0.06E | | P0.06 10 | BT_SWDCLK

V_POWER_SENSE | | P0.07 11

Note: SWDCLK Pulldown only for first nRF revision - later versions have them internally
VDD

P0.10 16
P0.11 17 | 1


PAD2 P0.04C | 7 8

Note: SWDCLK Pulldown only for first nRF revision - later versions have them internally

P0.21 40 | | | UNBAL3

P0.23 42 | GND


PAD3 P0.04D | 7 8


PAD5 | | P0.03 7
P0.04F | | P0.04 8
P0.05F | | P0.05 9
P0.07F | | P0.06 10 | BT_SWDCLK

P0.08F | P0.08 14
P0.09F | P0.09 15
P0.10F | P0.10 16

P0.11 17
P0.12 18


Note: SWDCLK Pulldown only for first nRF revision - later versions have them internally


3 | MODE FB CHRG | 8


Note:
Do not pull SWD pins up or down
nRF has internal pulls.




EXTAL0 L11 XTAL0 K11

XTAL2



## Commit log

2014-11-20 Initial commit for Wunderbar v1.3 hardware and datasheets
    [BOM-WunderBar_v103_BOTTOM.csv, BOM-WunderBar_v103_TOP.csv, Bill of Materials v1_3.xls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]
2014-11-20 PCB manufacture specifications
2015-11-10 added 3d bodies: QFN-48, 0402
    [WunderBar_v102b.PcbLib]
2018-03-06 Split Wunderbar schematics into individual PDFs
